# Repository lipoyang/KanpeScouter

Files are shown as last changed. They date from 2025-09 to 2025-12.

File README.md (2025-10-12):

# カンペスカウター
PowerPointのノート(カンペ)を単眼式グラスに映します。また、スライド送りなどの操作もできます。

## システム構成
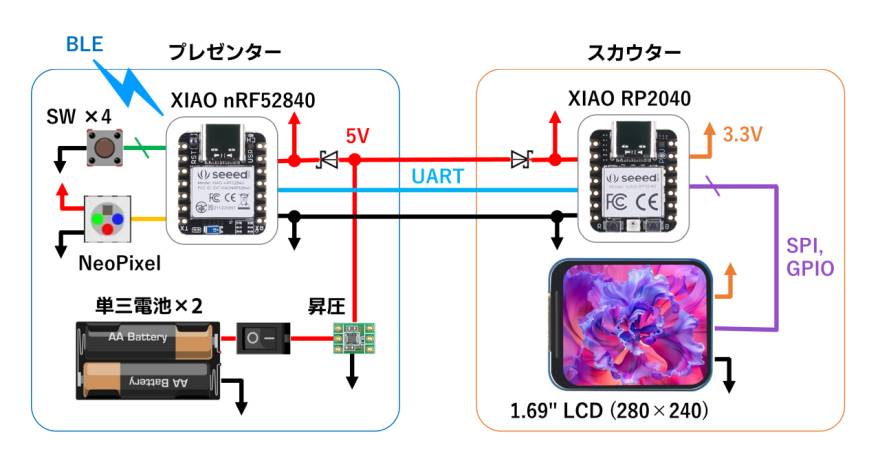
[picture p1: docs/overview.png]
システム構成


## 解説
* https://protopedia.net/prototype/7603

## ファイル
* [firmware/scouter](./firmware/scouter/) : スカウターのファームウェアのソースコード
* [firmware/presenter](./firmware/presenter/) : プレゼンターのファームウェアのソースコード
* [mechanical/scouter](./mechanical/scouter/) : スカウターの筐体設計データ
* [mechanical/presenter](./mechanical/presenter/) : プレゼンターの筐体設計データ
* [service](./service/) : PC側のサービスのソースコード (Python)
* [docs/circuit.md](docs/circuit.md) : 回路の資料
* [docs/BOM.md](docs/BOM.md) : おもな部品リスト

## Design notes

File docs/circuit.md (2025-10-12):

# 回路の資料

## 概要
概要

## LCDモジュールの結線
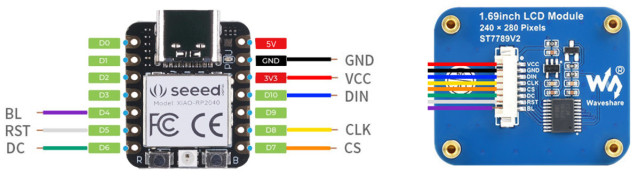
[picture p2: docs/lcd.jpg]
LCDモジュール


## レーザーモジュールの結線
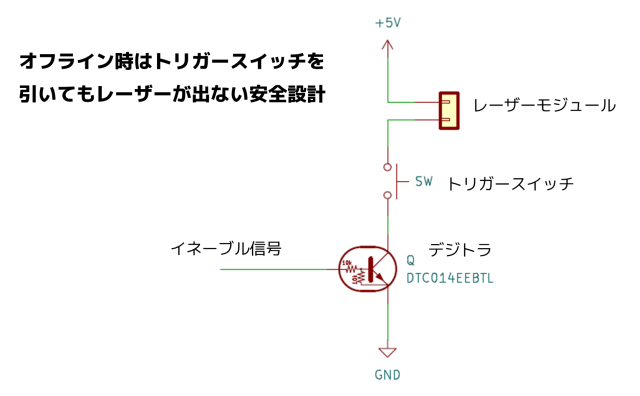
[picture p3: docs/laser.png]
レーザーモジュール


## 写真
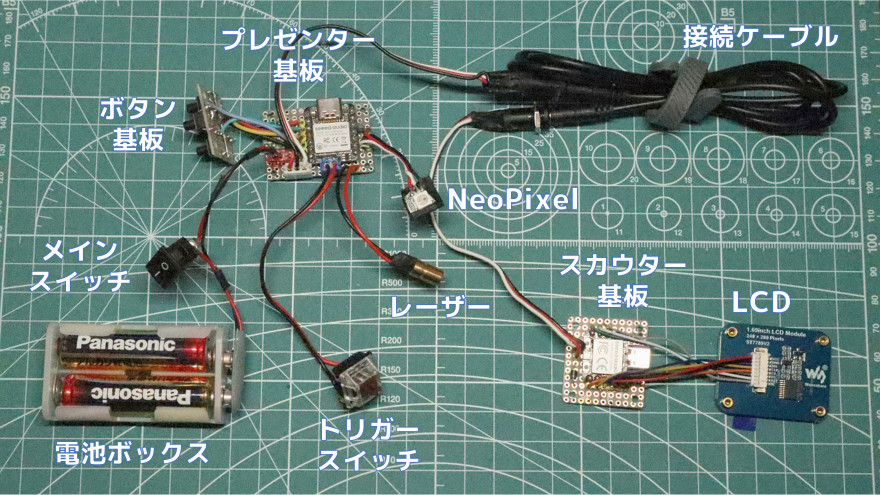
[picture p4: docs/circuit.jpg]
写真


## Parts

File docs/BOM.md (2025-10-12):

# おもな部品リスト

| 部品 | 購入先 | 備考 |
| ---- | ---- | ---- |
| XIAO nRF52840 | https://www.switch-science.com/products/8145 | プレゼンターのマイコン |
| XIAO RP2040 | https://www.switch-science.com/products/7634 | スカウターのマイコン |
| 1.69インチ 角丸LCDモジュール |https://www.switch-science.com/products/9030|240×280 SPI接続|
|XCL103使用5V出力昇圧DCDCコンバータ|https://akizukidenshi.com/catalog/g/g115097||
|3.5mmステレオミニジャックMJ-073H|https://akizukidenshi.com/catalog/g/g106257|2個|
|3.5mmステレオミニプラグオーディオケーブル|https://akizukidenshi.com/catalog/g/g113083|電源＆通信用|
|赤色ドットレーザーモジュール 6mm×17.5mm 1mW|https://akizukidenshi.com/catalog/g/g111821|レーザーポイント用|
|ロッカースイッチ|https://eleshop.jp/shop/g/gE36121/|電源スイッチ|
|茶軸キースイッチ|https://eleshop.jp/shop/g/gL25112/|レーザーポインタ用|
|ポリカハーフミラー|https://www.amazon.co.jp/dp/B00MJVS0B4||
|カードルーペ 5倍拡大 85mm×55mm|https://www.amazon.co.jp/dp/B0F66968H9|フレネルレンズ|
|ミニフラットトルクヒンジ HG-MF型|https://www.monotaro.com/p/0852/1415/||

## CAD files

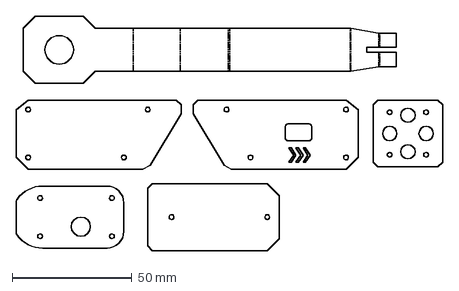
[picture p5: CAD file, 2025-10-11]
mechanical/presenter/DXF/Plates.dxf
178.4 x 98.0 mm

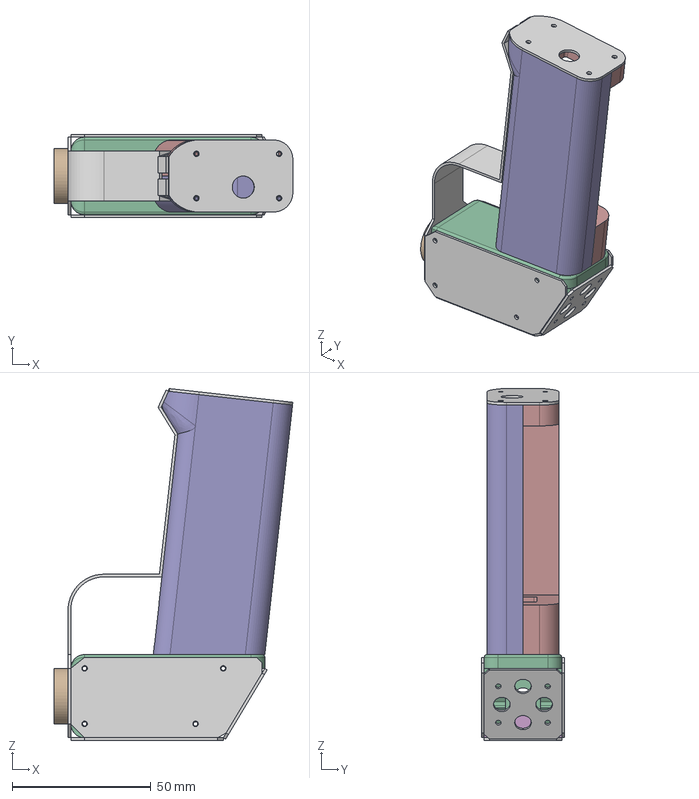
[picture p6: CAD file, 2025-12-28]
mechanical/presenter/Presenter.step
86.1 x 30.0 x 127.0 mm

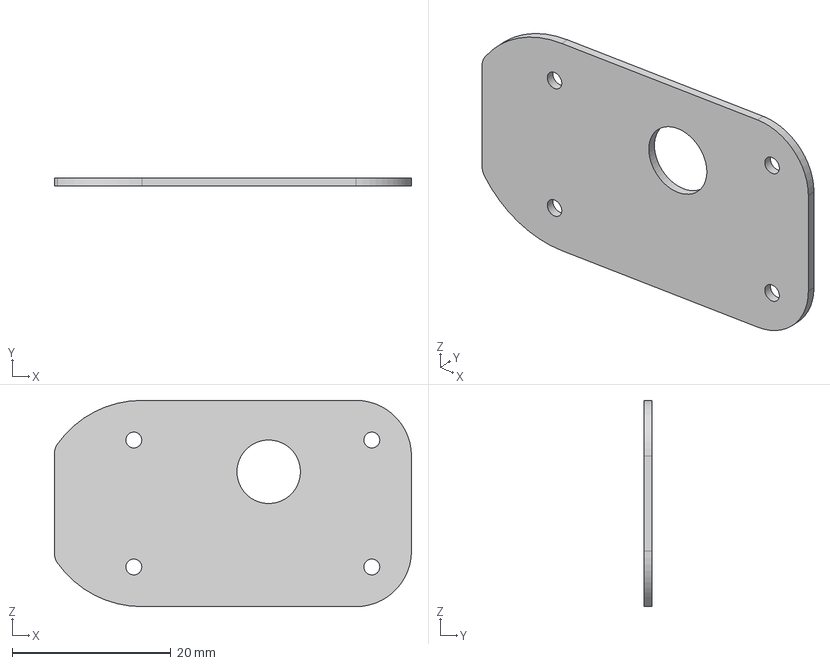
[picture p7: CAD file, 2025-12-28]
mechanical/presenter/Presenter_Plate/Component1.step
45.0 x 1.00 x 26.0 mm

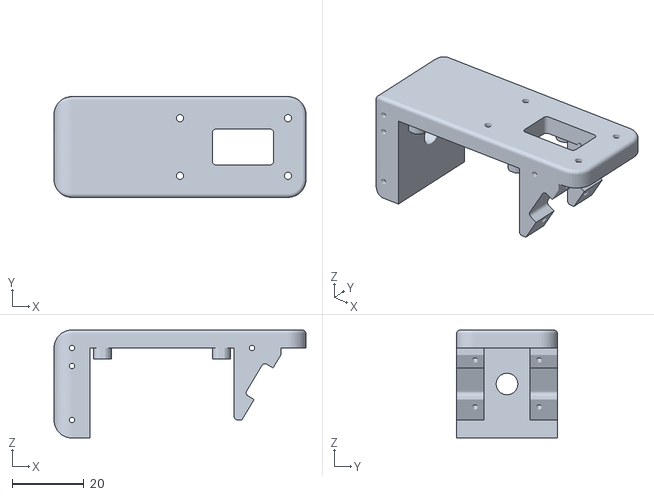
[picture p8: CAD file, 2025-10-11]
mechanical/presenter/STL/BottomShell.stl
70.0 x 28.0 x 30.0

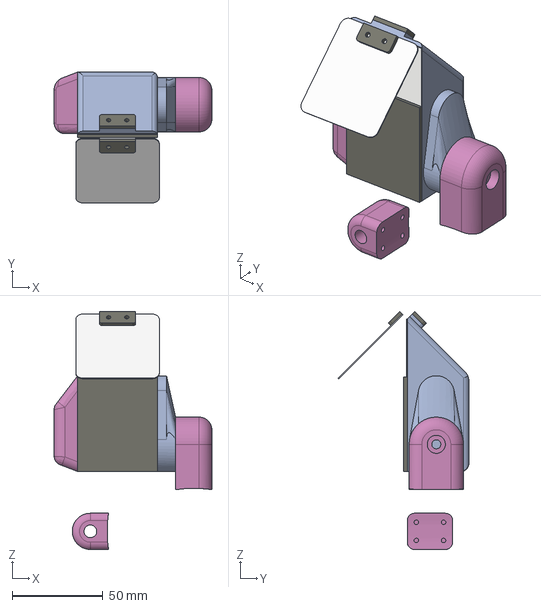
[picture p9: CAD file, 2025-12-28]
mechanical/scouter/Scouter.step
87.0 x 72.2 x 131.2 mm

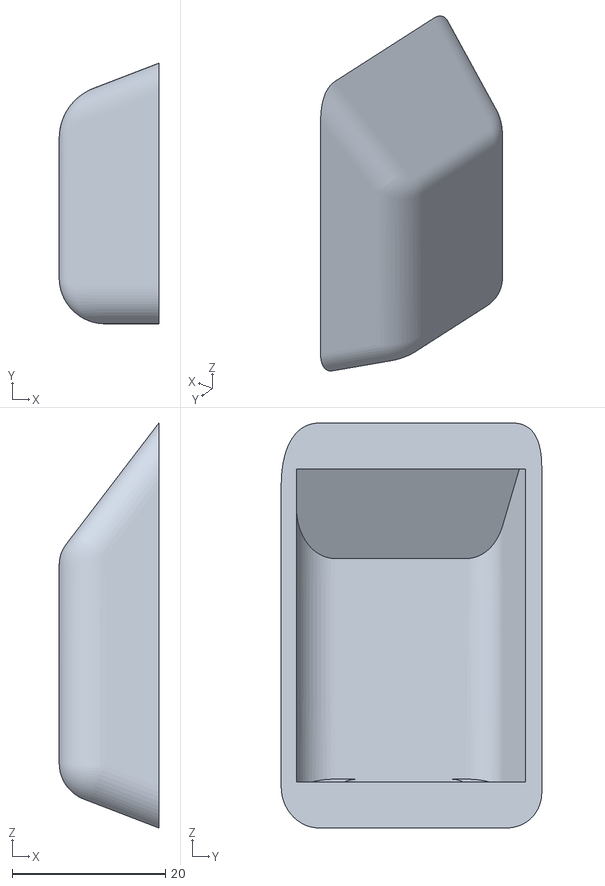
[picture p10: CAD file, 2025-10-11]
mechanical/scouter/STL/cover.stl
13.0 x 34.0 x 52.8

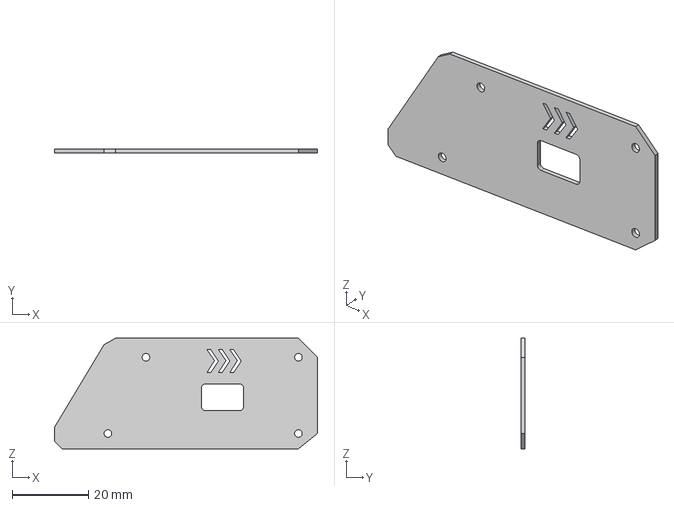
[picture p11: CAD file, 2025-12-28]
mechanical/presenter/Presenter_Plate/Component2.step
69.0 x 1.00 x 29.0 mm

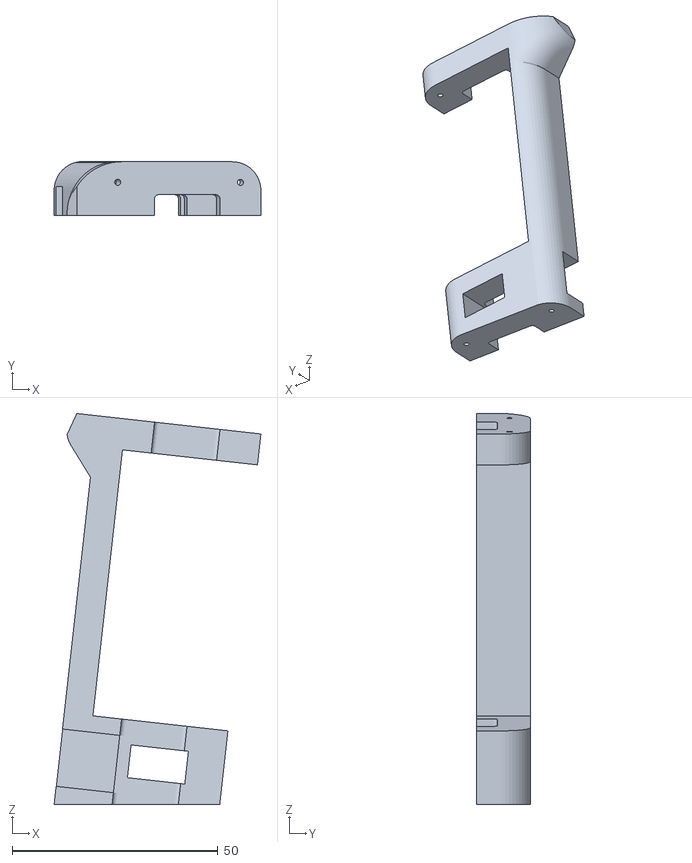
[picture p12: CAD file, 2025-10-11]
mechanical/presenter/STL/LeftShell.stl
50.2 x 13.0 x 95.0

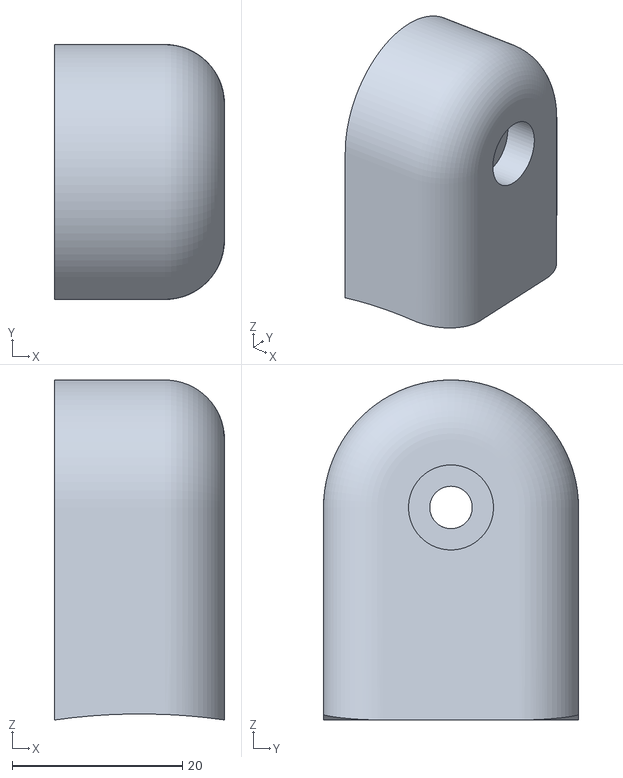
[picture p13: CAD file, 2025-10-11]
mechanical/scouter/STL/hinge.stl
20.0 x 30.0 x 40.0

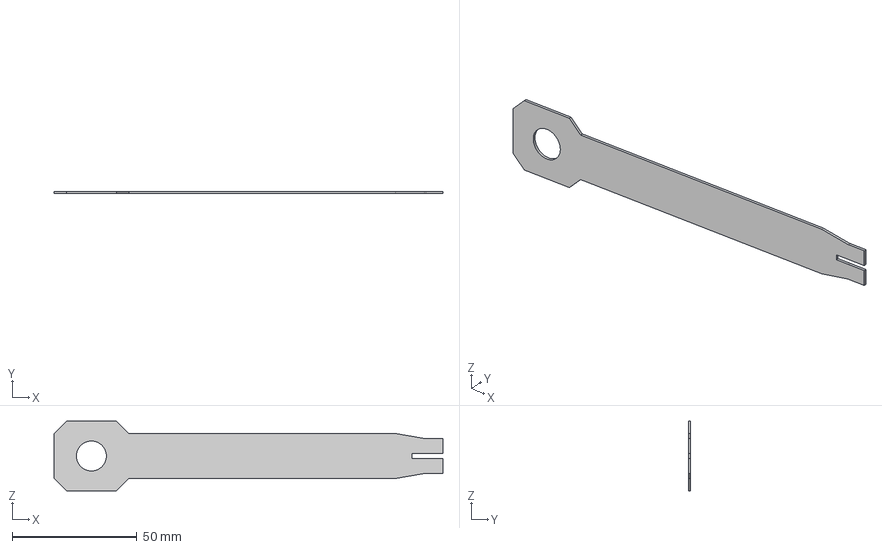
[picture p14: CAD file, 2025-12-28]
mechanical/presenter/Presenter_Plate/Component6.step
155.9 x 1.00 x 28.0 mm

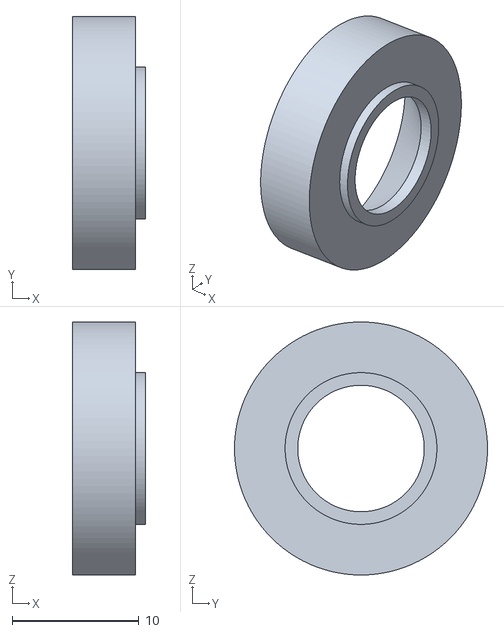
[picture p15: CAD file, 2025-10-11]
mechanical/presenter/STL/Aperture.stl
5.80 x 20.0 x 20.0

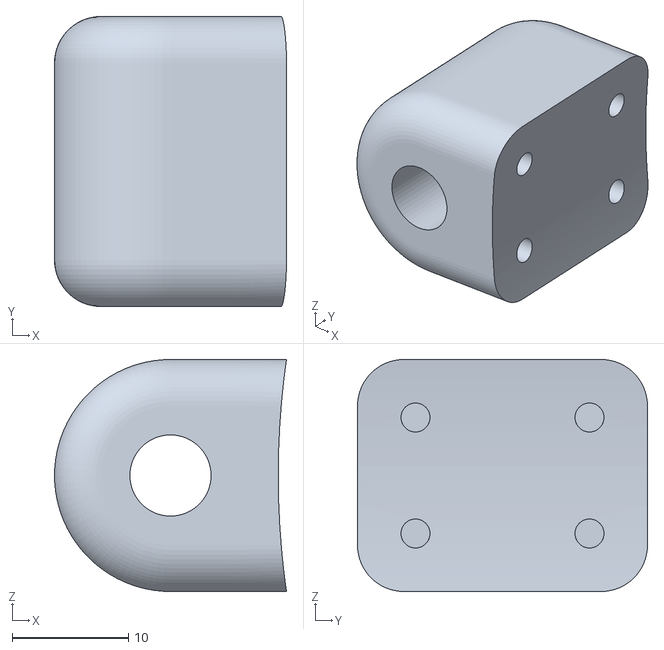
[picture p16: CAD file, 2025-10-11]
mechanical/scouter/STL/jack.stl
20.0 x 25.0 x 20.0

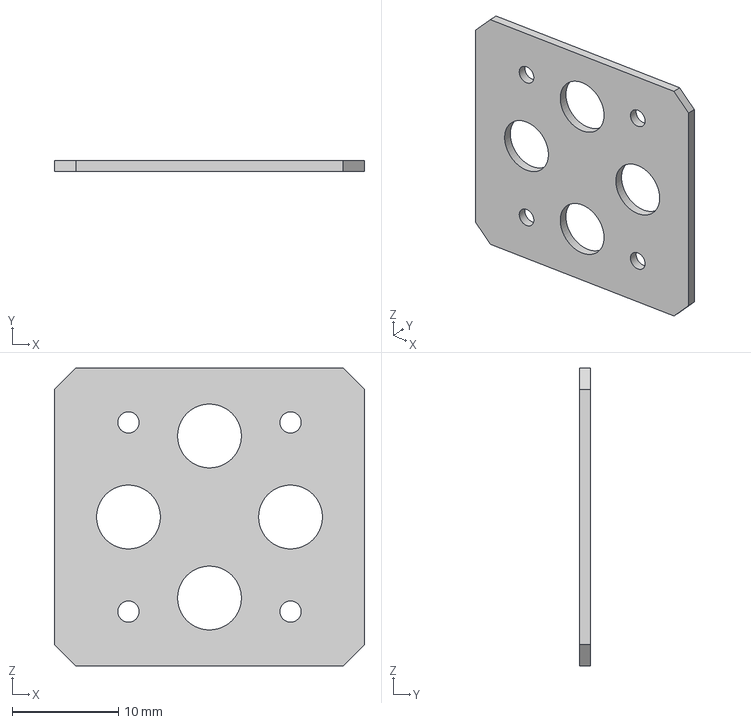
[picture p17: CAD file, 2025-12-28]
mechanical/presenter/Presenter_Plate/Component4.step
29.2 x 1.00 x 28.0 mm

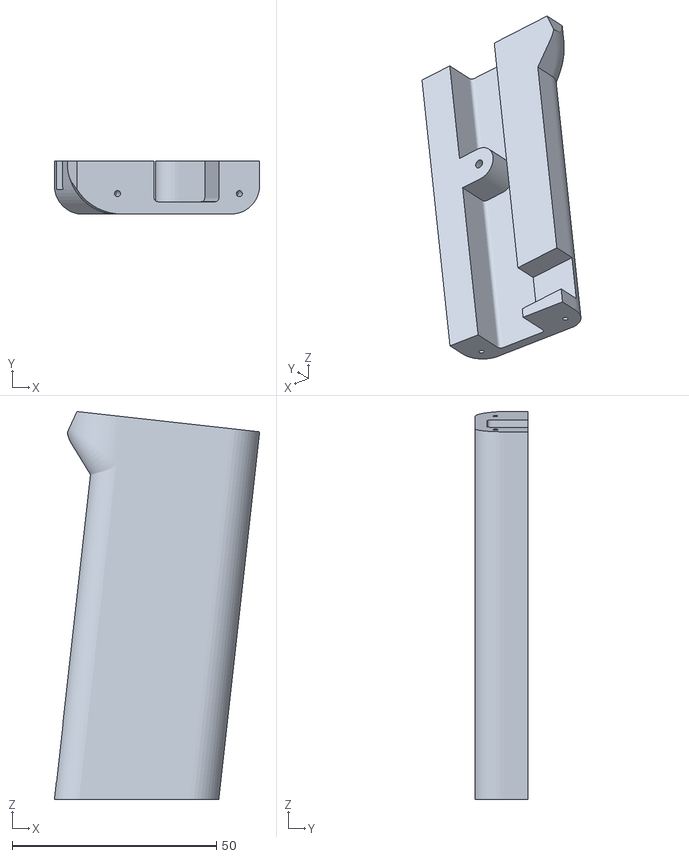
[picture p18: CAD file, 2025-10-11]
mechanical/presenter/STL/RightShell.stl
50.2 x 13.0 x 95.0

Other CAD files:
mechanical/scouter/STL/barrel.stl
mechanical/presenter/Presenter_Plate/Component5.step
mechanical/presenter/STL/TopBar.stl
mechanical/presenter/Presenter_Plate/Component3.step
mechanical/presenter/Presenter.f3d
mechanical/presenter/Presenter_Plate.f3d
mechanical/scouter/Scouter.f3d

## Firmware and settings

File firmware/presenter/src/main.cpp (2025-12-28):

#include <Arduino.h>
#include <ArduinoBLE.h>
#include <Adafruit_NeoPixel.h>
#include "PollingTimer.h"

// ピン割り当て
#define PIN_BATTERY   A0  // バッテリ電圧測定
#define PIN_BTN_PREV  D1  // Prevボタン
#define PIN_BTN_NEXT  D2  // Nextボタン
#define PIN_BTN_START D4  // Start/Endボタン
#define PIN_BTN_BLACK D3  // Blackout/Resumeボタン
#define PIN_LASER_EN  D5  // レーザー出力イネーブル
#define PIN_NEOPIXEL  D8  // フルカラーLED

// ボタン入力の値
enum ButtonInput {
  BTN_NONE = 0, // 押されていない
  BTN_NEXT,     // Nextボタン
  BTN_PREV,     // Prevボタン
  BTN_BLACK,    // Blackout/Resumeボタン
  BTN_START     // Start/Endボタン
};

// ポーリングタイマー
IntervalTimer buttonTimer;
IntervalTimer statusTimer;
IntervalTimer batteryTimer;

// PowerPointの状態
const uint8_t PPT_OFFLINE  = 0; // 未接続状態
const uint8_t PPT_NO_SLIDE = 1; // スライドショーが無い
const uint8_t PPT_STOPPED  = 2; // スライドショー停止中
const uint8_t PPT_RUNNING  = 3; // スライドショー実行中
const uint8_t PPT_BLACKOUT = 4; // ブラックアウト中

// PowerPointの状態を返す応答データの構造体
struct PptResponse {
  uint8_t status;       // PowerPointの状態
  uint16_t currentPage; // 現在のスライド番号（1から始まる）
  uint16_t totalPages;  // 総スライド数
  char note[300];       // 現在のスライドのノート(UTF-8, NULL終端)
}__attribute__((packed)); // パディングを防ぐ
PptResponse ppt;

// bool型の代わりに明示的に1バイトの整数型を使う
const uint8_t TRUE = 1;
const uint8_t FALSE = 0;

// BLEサービスとキャラクタリスティックの定義
BLEService        svcPptCtrl ("ba21ce66-9974-4ecd-b2e5-ab6d1497a7f0");
BLECharacteristic chrCommand ("ba21ce66-9974-4ecd-b2e5-ab6d1497a7f1",
                         BLENotify, 20);
BLECharacteristic chrResponse("ba21ce66-9974-4ecd-b2e5-ab6d1497a7f2",
                         BLEWrite, sizeof(PptResponse));

// フルカラーLED
Adafruit_NeoPixel pixels = Adafruit_NeoPixel(1, PIN_NEOPIXEL, NEO_GRB + NEO_KHZ800);
const int LED_BRIGHTNESS = 32; // 明るさ(0-255)

// バッテリー電圧の閾値
const float LOW_BATTERY  = 2.0f; // 低バッテリー警告

// ボタン入力の取得
ButtonInput get_button_input()
{
  const  int buttonPin [4] = {PIN_BTN_NEXT, PIN_BTN_PREV, PIN_BTN_BLACK, PIN_BTN_START};
  static int lastState [4] = {HIGH, HIGH, HIGH, HIGH};
  int nowState[4];
  ButtonInput ret = BTN_NONE;
  for(int i=0; i<4; i++) {
    nowState[i] = digitalRead(buttonPin[i]);
    if(lastState[i] == HIGH && nowState[i] == LOW) {
      if(ret == BTN_NONE) ret = (ButtonInput)(i + 1); // 若い番号のボタンを優先
    }
    lastState[i] = nowState[i];
  }
  return ret;
}

// スカウターに送信
void send_to_scouter()
{
  static char tx_buff[512];

  sprintf(tx_buff, "%c%X%04X%04X%s%c",
          0x02, // STX
          ppt.status      & 0x0F,
          ppt.currentPage & 0xFFFF,
          ppt.totalPages  & 0xFFFF,
          ppt.note,
          0x03 // ETX
        );
  Serial1.print(tx_buff);
}

// フルカラーLEDの制御
void set_led_color()
{
  const uint32_t colorTable[] = {
    0xFF0000, // PPT_OFFLINE  赤
    0xC04800, // PPT_NO_SLIDE 橙
    0x808000, // PPT_STOPPED  黄
    0x00FF00, // PPT_RUNNING  緑
    0x0000FF  // PPT_BLACKOUT 青
  };

  pixels.setPixelColor(0, colorTable[ppt.status]);
  pixels.show();
}

// バッテリー電圧の取得
void get_battery_voltage()
{
  static bool blink = false;

  int adc = analogRead(PIN_BATTERY);
  float v = (float)adc * (2.4f / 1023.0f) * 2.0f; // 分圧回路のため2倍する

  //Serial.print("Battery Voltage: ");
  //Serial.println(v);

  // 低バッテリー警告 (LEDを点滅させる)
  if (v <= LOW_BATTERY) {
    Serial.println("Low Battery Warning!");
    if (blink) {
      set_led_color();
    } else {
      pixels.setPixelColor(0, 0x000000);
      pixels.show();
    }
    blink = !blink;
  }else{
    blink = false;
    set_led_color();
  }
}

// 初期化
void setup()
{
  Serial.begin(115200);
  Serial.println("initializing...");

  // スカウターとの通信用のシリアルポートを初期化
  Serial1.begin(115200);
  while (!Serial1){ delay(10); }

  // ボタンピンの設定
  pinMode(PIN_BTN_NEXT,  INPUT_PULLUP);
  pinMode(PIN_BTN_PREV,  INPUT_PULLUP);
  pinMode(PIN_BTN_BLACK, INPUT_PULLUP);
  pinMode(PIN_BTN_START, INPUT_PULLUP);

  // レーザー出力イネーブルピンの設定
  pinMode(PIN_LASER_EN, OUTPUT);
  digitalWrite(PIN_LASER_EN, LOW); // レーザー出力無効

  // バッテリ電圧測定ピンの設定
  pinMode(PIN_BATTERY, INPUT);
  analogReference(AR_INTERNAL2V4); // VREF = 2.4V
  analogReadResolution(10);        // 10bit A/D

  // BLEの初期化
  if (!BLE.begin()) {
    Serial.println("starting BLE failed!");
    while (1);
  }

  // MACアドレスを取得して表示
  String addr = BLE.address();
  Serial.print("Device MAC Address: ");
  Serial.println(addr);

  // BLEデバイスの設定
  //BLE.setConnectionInterval(6, 80); // 7.25ms - 100ms
  BLE.setLocalName("KanpeScouter");
  BLE.setAdvertisedService(svcPptCtrl);
  svcPptCtrl.addCharacteristic(chrCommand);   // コマンド送信用
  svcPptCtrl.addCharacteristic(chrResponse);  // 応答受信用
  BLE.addService(svcPptCtrl);
  BLE.advertise();

  // NeoPixelの初期化
  pixels.begin();
  pixels.setBrightness(LED_BRIGHTNESS);

  Serial.println("KanpeScouter ready");
}

// メインループ
void loop()
{
  // セントラルから接続されたら
  BLEDevice central = BLE.central();
  if (central)
  {
    Serial.print("Connected to central: ");
    Serial.println(central.address());

    // ポーリングタイマーの設定
    buttonTimer.set(10);
    statusTimer.set(1000);
    batteryTimer.set(500);
    bool toGetStatus = true;

    // レーザー出力有効
    digitalWrite(PIN_LASER_EN, HIGH);

    // 接続が切れるまで
    while (central.connected())
    {
      // ボタン入力の監視
      if (buttonTimer.elapsed()) {
        ButtonInput btn = get_button_input();
        char* command = (char*)"";
        bool isCommand = true;
        switch(btn) {
          case BTN_NEXT:  command = (char*)"next";  break;
          case BTN_PREV:  command = (char*)"prev";  break;
          case BTN_BLACK: command = (char*)"black"; break;
          case BTN_START: command = (char*)"start"; break;
          default:
            isCommand = false;
            break;
        }
        if(isCommand) {
          chrCommand.writeValue(command);
          Serial.print("Notify: ");
          Serial.println(command);
        }
      }
      // 接続直後には状態取得コマンドを送る
      if (toGetStatus && statusTimer.elapsed()) {
        char *command = (char*)"check";
        chrCommand.writeValue(command);
        Serial.print("Notify: ");
        Serial.println(command);
      }
      // 応答受信
      if (chrResponse.written()) {
        ppt = *(PptResponse*)chrResponse.value();
        ppt.note[sizeof(ppt.note)-1] = '\0'; // 念のためNULL終端を保証
        Serial.println("Written:");
        Serial.println(ppt.status);
        Serial.println(ppt.currentPage); 
        Serial.println(ppt.totalPages);
        Serial.println(ppt.note);

        // スカウターに送信
        send_to_scouter();
        // フルカラーLEDの制御
        set_led_color();

        toGetStatus = false; // 状態取得コマンドを送るフラグをクリア
      }
      // バッテリー電圧の取得
      if (batteryTimer.elapsed()) {
        get_battery_voltage();
      }
    } // while (central.connected()) ココマデ

    Serial.print("Disconnected from central: ");
    Serial.println(central.address());
  } // if (central) ココマデ

  // レーザー出力無効
  digitalWrite(PIN_LASER_EN, LOW);

  // 切断状態
  ppt.status = PPT_OFFLINE;
  ppt.currentPage = 0;
  ppt.totalPages = 0;
  ppt.note[0] = '\0';

  // スカウターに送信
  send_to_scouter();
  // フルカラーLEDの制御
  set_led_color();

  // バッテリー電圧の取得
  get_battery_voltage();

  delay(500);
}

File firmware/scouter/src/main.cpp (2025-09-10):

#include <Arduino.h>
#include "PollingTimer.h"

// ピン割り当て
#define TFT_MISO      -1 // 接続しない
#define TFT_MOSI      D10
#define TFT_SCLK      D8
#define TFT_CS        D7
#define TFT_DC        D6
#define TFT_RST       D5
#define TFT_BL        D4
#define UART1_RX      D3  // P29
#define UART1_TX      D2  // P28

// 画面デバイスの定義
#include <LovyanGFX.hpp>
class LGFX : public lgfx::LGFX_Device
{
  lgfx::Panel_ST7789  _panel_instance;
  lgfx::Bus_SPI       _bus_instance;
  lgfx::Light_PWM     _light_instance;

public:
  LGFX(void)
  {
    { // SPIバスの設定
      auto cfg = _bus_instance.config();

      cfg.spi_host = 0;          // 使用するSPIを選択
      cfg.spi_mode = 3;          // SPI通信モード (0 ~ 3)
      cfg.freq_write = 40000000; // 送信時のSPIクロック
      cfg.freq_read = 20000000;  // 受信時のSPIクロック

      cfg.pin_sclk = TFT_SCLK;
      cfg.pin_mosi = TFT_MOSI;
      cfg.pin_miso = TFT_MISO;
      cfg.pin_dc   = TFT_DC;

      _bus_instance.config(cfg);
      _panel_instance.setBus(&_bus_instance);
    }
    { // 表示パネルの設定
      auto cfg = _panel_instance.config();

      cfg.pin_cs   = TFT_CS;
      cfg.pin_rst  = TFT_RST;
      cfg.pin_busy = -1; // 接続しない

      cfg.panel_width  = 240;   // 幅
      cfg.panel_height = 280;   // 高さ
      cfg.offset_x = 0;         // X方向オフセット
      cfg.offset_y = 20;        // Y方向オフセット (なぜか20ドットずれる)

      cfg.invert = true;        // 明暗が反転する場合 true

      _panel_instance.config(cfg);
    }
    { // バックライトの設定
      auto cfg = _light_instance.config();

      cfg.pin_bl = TFT_BL;
      cfg.invert = false;       // 輝度が反転する場合 true
      cfg.freq   = 44100;       // バックライトのPWM周波数
      cfg.pwm_channel = 0;      // 使用するPWMのチャンネル番号 (注意!)

      _light_instance.config(cfg);
      _panel_instance.setLight(&_light_instance);
    }
    setPanel(&_panel_instance);
  }
};
#include <LGFX_TFT_eSPI.hpp>
TFT_eSPI tft = TFT_eSPI();
TFT_eSprite sprite_h = TFT_eSprite(&tft); // 上段スプライト(状態表示)
TFT_eSprite sprite_t = TFT_eSprite(&tft); // 上段スプライト(経過時間表示)
TFT_eSprite sprite_b = TFT_eSprite(&tft); // 本文スプライト
TFT_eSprite sprite_f = TFT_eSprite(&tft); // 下段スプライト

// フォントサイズ
const int FONT_SIZE = 24;

// シリアル受信バッファと状態
enum {
  RX_IDLE = 0, // 受信待ち
  RX_RECV,     // 受信中
};
char rx_buff[512];
int rx_index = 0;
int rx_state = RX_IDLE;

// PowerPointの状態
const uint8_t PPT_OFFLINE  = 0; // 未接続状態
const uint8_t PPT_NO_SLIDE = 1; // スライドショーが無い
const uint8_t PPT_STOPPED  = 2; // スライドショー停止中
const uint8_t PPT_RUNNING  = 3; // スライドショー実行中
const uint8_t PPT_BLACKOUT = 4; // ブラックアウト中

// 状態表示の文字列
const char* PPT_STATUS_STR[] = {
  "OFFLINE",
  "NO SLIDE",
  "STOPPED",
  "RUNNING",
  "BLACKOUT"
};
// 状態表示の文字色
const uint16_t PPT_STATUS_COLOR[] = {
  TFT_RED,
  TFT_ORANGE,
  TFT_YELLOW,
  TFT_GREEN,
  TFT_CYAN
};

// PowerPointの状態を返す応答データの構造体
struct PptResponse {
  uint8_t status;       // PowerPointの状態
  uint16_t currentPage; // 現在のスライド番号（1から始まる）
  uint16_t totalPages;  // 総スライド数
  char note[300];       // 現在のスライドのノート(UTF-8, NULL終端)
};
PptResponse ppt;

// 経過時間表示用
bool is_running = false;    // スライドショー実行中か
uint32_t elapsed_time = 0;  // 経過時間 [秒]
IntervalTimer onesec_timer; // 1秒タイマー

// 初期化
void setup()
{
  Serial.begin(115200);
  Serial.println(F("Scouter for PowerPoint"));

  // Serial1のTXをGPIO4, RXをGPIO5に割り当て
  Serial1.setTX(UART1_TX);
  Serial1.setRX(UART1_RX);
  Serial1.begin(115200);

  // 画面の初期化
  tft.init();
  tft.setRotation(1);     // 画面回転(横向き)
  tft.setBrightness(255); // バックライト100%(全点灯)
  tft.fillScreen(TFT_BLACK);

  // スプライトの初期化
  int screenWidth = tft.width();
  int screenHeight = tft.height();
  sprite_h.createSprite(screenWidth / 2 - FONT_SIZE, FONT_SIZE);
  sprite_t.createSprite(screenWidth / 2 - FONT_SIZE, FONT_SIZE);
  sprite_b.createSprite(screenWidth, screenHeight - FONT_SIZE * 2);
  sprite_f.createSprite(screenWidth - FONT_SIZE * 2, FONT_SIZE);
}

// 経過時間の表示
void show_time()
{
  // 経過時間
  int min = elapsed_time / 60;
  int sec = elapsed_time % 60;

  // フォント
  const lgfx::v1::IFont *font = &fonts::lgfxJapanGothic_24;

  // 経過時間の表示更新
  sprite_t.setFont(font);
  sprite_t.setTextColor(PPT_STATUS_COLOR[ppt.status], TFT_BLACK);
  sprite_t.fillScreen(TFT_BLACK);
  sprite_t.setCursor(0, 0);
  sprite_t.setTextWrap(false);
  sprite_t.printf("%3d:%02d", min, sec);
  sprite_t.pushSprite(tft.width() / 2, 0);
}

// 画面表示
void show_status()
{
  // フォント
  const lgfx::v1::IFont *font = &fonts::lgfxJapanGothic_24;

  // 上段の表示更新 (状態表示)
  sprite_h.setFont(font);
  sprite_h.setTextColor(PPT_STATUS_COLOR[ppt.status], TFT_BLACK);
  sprite_h.fillScreen(TFT_BLACK);
  sprite_h.setCursor(0, 0);
  sprite_h.setTextWrap(false);
  sprite_h.print(PPT_STATUS_STR[ppt.status]);
  sprite_h.pushSprite(FONT_SIZE, 0);

  // 上段の表示更新 (経過時間表示)
  show_time();

  // 本文の表示更新
  sprite_b.setFont(font);
  sprite_b.setTextColor(TFT_WHITE, TFT_BLACK);
  sprite_b.fillScreen(TFT_BLACK);
  sprite_b.setCursor(0, 0);
  sprite_b.setTextWrap(true);
  sprite_b.println(ppt.note);
  sprite_b.pushSprite(0, FONT_SIZE);

  // 下段の表示更新
  sprite_f.setFont(font);
  sprite_f.setTextColor(PPT_STATUS_COLOR[ppt.status], TFT_BLACK);
  sprite_f.fillScreen(TFT_BLACK);
  sprite_f.setCursor(sprite_f.width() / 2 - FONT_SIZE * 3, 0);
  sprite_f.setTextWrap(false);
  sprite_f.printf("%3d / %d", ppt.currentPage, ppt.totalPages);
  sprite_f.pushSprite(FONT_SIZE, tft.height() - FONT_SIZE);
}

// プレゼンターから受信したデータの処理
void on_recv_data(const char* data)
{
  Serial.print("RX:");
  Serial.println(rx_buff);

  // メッセージの解釈
  int result = sscanf(rx_buff,
    "%1hhx%4hhx%4hhx",
    &ppt.status,       // [0]
    &ppt.currentPage,  // [1]-[4]
    &ppt.totalPages    // [5]-[8]
  );
  if(result != 3){
    Serial.println("ERROR: sscanf");
    return;
  }
  memcpy(ppt.note, &rx_buff[9], sizeof(ppt.note)-1);
  ppt.note[sizeof(ppt.note)-1] = '\0'; // 念のためNULL終端

  // 経過時間のリスタート/リセット
  if(ppt.status >= PPT_RUNNING){
    if(!is_running){
      // スライドショーが開始されたら経過時間をリスタート
      is_running = true;
      elapsed_time = 0;
      onesec_timer.set(1000);
    }
  }else{
    // スライドショー実行中でなければ経過時間はリセット
    is_running = false;
    elapsed_time = 0;
  }

  // 画面表示の更新
  show_status();
}

// プレゼンターからのシリアル受信処理
void serial_com()
{
  while(Serial1.available() > 0){
    char c = Serial1.read();
    switch(rx_state){
      // 受信待ち
      case RX_IDLE:
        if(c == 0x02){ // STX
          rx_state = RX_RECV;
          rx_index = 0;
        }
        break;
      // 受信中
      case RX_RECV:
        if(c == 0x02){ // STX (途中でSTXが来たら最初から)
          rx_index = 0;
        }
        else if(c == 0x03){ // ETX
          rx_state = RX_IDLE;
          // 受信したデータの処理
          rx_buff[rx_index] = '\0';
          on_recv_data(rx_buff);
        }
        else{
          rx_buff[rx_index] = c;
          rx_index++;
          if(rx_index >= sizeof(rx_buff)-1){
            rx_index = sizeof(rx_buff)-1;
          }
        }
        break;
      default:
        rx_state = RX_IDLE;
        break;
    }
  }
}
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

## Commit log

2025-09-18 update presenter (add Laser)
2025-09-18 update presenter (add low battery detection)
2025-10-11 add mechanical designs
    [Aperture.stl, BottomShell.stl, LeftShell.stl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]
2025-10-11 add 3D design
    [Presenter.step, Scouter.f3d, Scouter.step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]
2025-10-12 add BOM
2025-10-12 add circuit.md
2025-12-28 modify 3D data
    [Component1.step, Component2.step, Component3.step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]
